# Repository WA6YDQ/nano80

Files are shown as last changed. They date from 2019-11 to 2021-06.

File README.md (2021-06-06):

nano80 - An Arduino powered 8080 single board computer.
======================

This is an 8080 simulator/emulator for an Arduino Nano. It uses about 
12K of memory and appx 600 bytes of ram (dynamic memory).

This is a front panel programmable computer, something like the 
single board trainers used in the 70's and 80's in colleges. 
Using a few switches and push buttons, along with some led's 
and a 1x8 lcd display, you can program the memory, step thru 
and view memory and run 8080 programs. There is a bootloader 
that allows loading an 8080 object coded program over the serial 
port as well as some development programs written in c.

See the schematic for wiring.

There is more detail on my blog at landfallnet.blogspot.com
Look for the nano80 entry.

I use a 32Kx8 FRAM for main memory. This slows it down a lot, but 
it gives you lots of room to play around. If you want more speed, 
change the fram.[read8/write8] to mem[] and set up about 1K of 
arduino ram. Doing this gives a speed improvement of about 4.5 times.

The serial port is defined so that your 8080 has a serial port in 
addition to 8 led's and 8 toggle switches for input/output.

The input/output ports are defined as follows:
- IN 0x00 is the toggle switches
- IN 0x01 is the serial port using the arduino
- IN 0x02 returns the number of available bytes on the serial port

- OUT 0x00 is the 8 LED's 
- OUT 0x01 is the serial port using the arduino

=========================
NOTE: The .c programs are utility programs that run on a linux computer
and are not part of the arduino code. Only put the .ino file into the
arduino workspace when building this project. 
==========================

------------------------------

I posted an 8080 opcode tester in diag.asm. This is a brute-force
8080 opcode tester. I've run this over several days with good results
(after I fixed the bugs). 

------------------------------

There is a boot loader in software to load intel .hex files 
into the nano80 memory. Loading more than a few bytes via switches
and lights get old fast. The boot loader lets you assemble large 
programs and upload then. See README.bootloader for use.

There are two programs used to create and send the .hexfiles:
- ihex.c
- upload.c

ihex converts the .com output of the assembler into intel .hex files.
upload is a serial based uploader that allows for the slow memory 
access of the FRAM memory chip.

To compile these 2 programs:
- cc -o ihex ihex.c
- cc -o upload upload.c

-----------------------------------

Also here is asm80.c

This is a command line 8080 assembler I wrote some time ago. Tested 
under Linux, compiled with gcc. To compile: 

- cc -o asm80 asm80.c

asm80 uses standard intel 8080 nmemonics. It is NOT a macro assembler.

-----------------------------------

There are some 8080 source code files for testing the system. 

- sertest.asm is a simple test of the serial port. 
- cylon.asm is a flashy lights program.

-----------------------------------

There is a program called dump.c This is a hex dump program 
I wrote to view object code files. 

Compile with:

- cc -o dump dump.c

-----------------------------------

MIT license applies to all files herein unless otherwise noted.

--Kurt

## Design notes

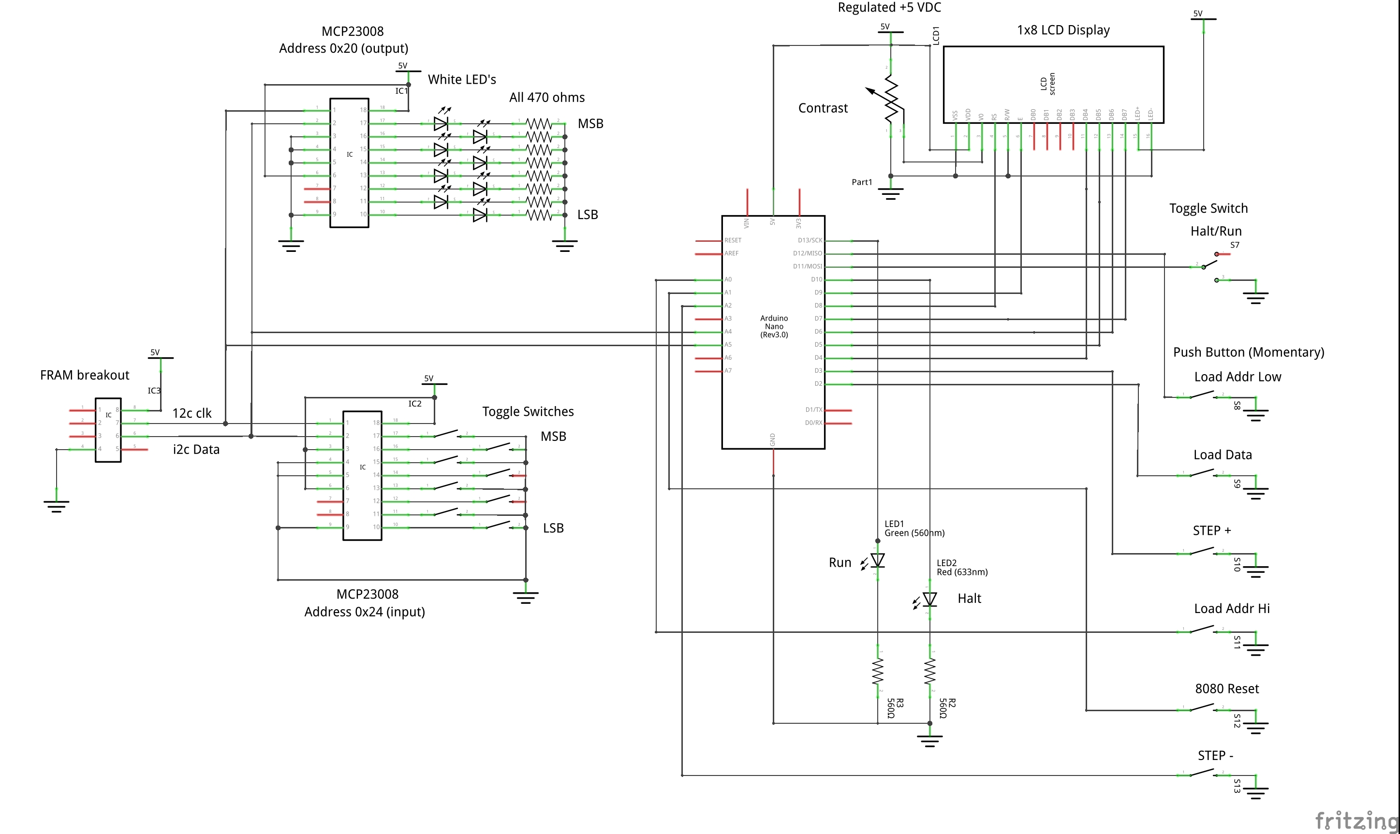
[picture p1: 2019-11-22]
nano80_schem.jpg

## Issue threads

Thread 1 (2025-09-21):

Arduino nanocircuits

alexanderbedoyahincapie058-sudo, 2025-09-21:

WA6YDQ, 2025-09-22:
No issue specified. Closing.

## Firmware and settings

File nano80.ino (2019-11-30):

/*
 * This is an 8080 simulator specifically for the
 * Arduino Nano. It uses an I2C 32K byte FRAM chip for main memory,
 * a front panel to program memory includinga 1x8 LCD, 8 toggle switches,
 * and 6 momentary buttons. The memory (non-volatile) is from 0000h thru 7fffh.
 * There is boot loader code to remotely program memory.
 * This makes a very good 8080 software development tool and play toy.
 * 
 * (C) k theis 11/2019 MIT license applies.
 * 
 * version 1.05  11/30/2019 DAA passes. All op codes passed the diag.asm check.
 * version 1.04e 11/29/2019 All instructions passed op code checker xcpt DAA.
 * version 1.04d 11/26/2019 Set parity flag (P) based on parity test, fix RLC,RRC,RAL
 * version 1.04c 11/26/2019 Change docs, removed unused vars. No functional changes.
 * version 1.04b 11/25/2019 fix things in debug() 
 * version 1.04a 11/25/2019 SBB: fix it right this time
 * version 1.04  11/25/2019 SBB: a=a-n-C change, added intel HEX bootloader. Uses custom backend
 * uploader w/20msec delays between HEX lines. Needed for FRAM.
 * version 1.03  11/22/2019 removed all bootloader code. fram access is too slow for it
 * version 1.02c 11/21/2019 fix issue with conditional return, shorten code
 * version 1.02b 11/21/2019 max baud 1200, fixed boot loader & serial read()
 * version 1.02a 11/20/2019 fixed bootloader byte sequence
 * version 1.02 11/20/2019 wrote inline bootloader, load/reset starts it
 * version 1.01 11/20/2019 minor change to reset()
 * version 1.0  11/18/2019 released to wild
 */

#include <string.h>
#include <LiquidCrystal.h>
#include <Wire.h>
#include <avr/pgmspace.h>
#include "Adafruit_FRAM_I2C.h"

#define MAXMEM 32768     // maximum RAM size
#define SERIALSPEED 9600 // Serial.write works till the buffer is filled.
                         // Because of slowwwww FRAM memory access, don't expect much. 
#define DEBUG 0          // 0: no debugging serial output (except at halt), 
                         // 1: show address and opcode on serial port while running

#define HALTLED 10       // D10 Halt LED
#define RUNLED 13        // D13 Run LED
#define RUNHALT 11       // D11 runhalt switch run=0, halt=1 (toggle switch)
#define RESET A1         // D13 reset switch (momentary switch)
#define LDAH A0          // load address high (momentary switch)
#define LDAL 12          // load address lo (momentary switch)
#define STEP 3           // increment address, show data (momentary switch)
#define LOAD 2           // load data into memory, step address (momentary switch)
#define STEPMINUS A2     // decrement address, show data (momentary switch)

#define e 9              // LCD display (1x8) control lines
#define rs 8
#define d7 7
#define d6 6
#define d5 5
#define d4 4

#define DEBOUNCE 80     // push button switch debounce time

uint16_t    PC, A, BC, DE, HL, StackP, temp, carry, hi, lo;
uint8_t     OP;
bool        C, Z, P, AC, S, INTE;


LiquidCrystal lcd(rs,e,d4,d5,d6,d7);
Adafruit_FRAM_I2C fram = Adafruit_FRAM_I2C();

/* send debugging info to the serial port */
void debug() {
    char crnt[strlen("PC:%4.4X  OP:%2.2X")+1];
    sprintf(crnt,"PC:%4.4X  OP:%2.2X",PC,OP);
    Serial.println(crnt);
    char regs[strlen("A:%2.2X  BC:%4.4X  DE:%4.4X  HL:%4.4X  SP:%4.4X")+1];
    sprintf(regs,"A:%2.2X  BC:%4.4X  DE:%4.4X  HL:%4.4X  SP:%4.4X",A,BC,DE,HL,StackP);
    Serial.println(regs);
    char flags[strlen("Z:%d  C:%d  S:%d  AC:%d  P:%d")+1];
    sprintf(flags,"Z:%d  C:%d  S:%d  AC:%d  P:%d",Z,C,S,AC,P);
    Serial.println(flags);
    Serial.println();
    return;
}

/* clear FRAM, then load the boot loader in hi memory */
void clrmem() {     // called from reset()
    uint16_t adr;
    uint8_t dat;
    lcd.home();
    lcd.print("Clr Mem ");
    /* first clear FRAM */
    for (adr=0; adr < 32768; adr++) 
        fram.write8(adr,0);
    lcd.clear();
    return;
}

/* read intel .hex records from the serial port  
 *  This needs a custom uploader (see upload.c in repository) to properly
 *  deal with the FRAM wait states. The uploader sends an intel HEX file
 *  line by line with a 20msec delay at the end of each line. This allows 
 *  time to send the data to the FRAM memory as well as dealing with the 
 *  limited ram buffer for the serial port.
 */
void bootload () {

    int cnt, bytenum, addr, recordtype, dat, cd = 0;
    uint8_t record[80];
    uint8_t tdat[4] = {0,0,0,0};
    lcd.home();
    lcd.print("booting ");
    /* main read & store loop */

    while (Serial.available() == 0) continue;   // wait for data  
dlloop:
    for (cnt=0;cnt<79;cnt++) record[cnt]=0;
    cd = 0;
    cnt = 0;
    if (Serial.available()==0) goto dlloop;
    while (1) {
        dat = Serial.read();
        if (dat == -1) continue;    // wait till data arrives
        if (dat == 0x3a) continue;  // start char
        if (dat == '\n') break;
        tdat[cd]=dat & 0xff;
        cd++;
        if (cd<2) continue;         // combine bytes
        cd = 0;
         if (tdat[0] > 0x39) tdat[0]-=7;        // convert from ascii
         tdat[0]-=0x30;
         if (tdat[1] > 0x39) tdat[1]-=7;
         tdat[1]-=0x30;
        record[cnt] = ((16*tdat[0]) + tdat[1]);
        output(record[cnt],0);      // display byte on LED's (eye candy)
        if (cnt==0) bytenum = record[0];    // 0 because we skip the ':'
        /* count=0  address=1-2   record type=3  bytenum+1=checksum */
        if (cnt==3) recordtype = record[3];
        cnt++;
    }
    if (recordtype == 0) {      // load data from DATA record type
        // now store the record
        addr = (256*record[1])+record[2];
        for (cd=0; cd<bytenum;cd++) {
            fram.write8(addr,record[cd+4]);
            addr++;
        }  
        goto dlloop;
    }
     // ignore record type other than 0 for now (will need for 8086 etc)

    output(0,0);        // clear the LED's
    lcd.home();
    lcd.print(addr,HEX);
    lcd.print("        ");
    delay(1000);
    lcd.home();
    lcd.print("Done    ");
    delay(1000);
    
    lcd.clear();
    return;
}


/* reset the processor */
void reset(void) {
    digitalWrite(RUNLED,0);     // turn OFF run led

    if (digitalRead(STEPMINUS) == 0) {  // press STEPMINUS and reset will
        clrmem();                       // clear memory (FRAM)
        while (digitalRead(STEPMINUS) == 0) { 
            delay(DEBOUNCE);
        }
        delay(DEBOUNCE);
    }

    if (digitalRead(LOAD) == 0) {
        bootload();
        while (digitalRead(LOAD) == 0) {
            delay(DEBOUNCE);
        }
        delay(DEBOUNCE);
    }


    // normal reset
    PC = A = BC = DE = HL = StackP = 0; // The real 8080 doesn't clear these
    Z = C = S = AC = P = INTE = 0;      // on reset. Remove this if you want.
                                        // (The Z80 DOES set some to FFFFh, ie. SP)

    digitalWrite(HALTLED, 0);   // turn OFF HALT led
    while (digitalRead(RESET) == 0) {
        delay(DEBOUNCE);
    }
    delay(DEBOUNCE);
    return;
}


/* show address/data (based on PC/OP) on a 1x8 LCD */
void updatelcd() {
    char lcd_addr[5];
    char lcd_data[3];
    lcd.clear();
    sprintf(lcd_addr,"%4.4X",PC);
    if (PC >= MAXMEM)   // account for missing memory
            OP=0x00;
        else
            OP = fram.read8(PC);
    sprintf(lcd_data,"%2.2X",OP);
    lcd.setCursor(0,0);
    lcd.print(lcd_addr);
    lcd.setCursor(6,0);
    lcd.print(lcd_data);
    return;
}

byte readSwitchPort() {
    byte val;
    Wire.beginTransmission(0x24); // address of input port
        Wire.write(0x09);
        Wire.endTransmission();
        Wire.requestFrom(0x24,1);
        while (Wire.available()) {            
            val = Wire.read();
        }
    return val;
}

void frontpanel() {
    uint16_t ADR;
    byte DAT;
    digitalWrite(RUNLED,0);     // turn off run led
    updatelcd();
    while (digitalRead(RUNHALT)==1) {   // loop while in stop mode
        if (digitalRead(RESET) == 0) {   // reset pressed?
            reset();
            return;
        }
        if (digitalRead(LDAH)==0) {     // Load Address high
            ADR = readSwitchPort();
            PC = (PC &0xFF) + (ADR*256);
            updatelcd();
            while (digitalRead(LDAH)==0) {
                delay(DEBOUNCE);
                continue;
            }
            delay(DEBOUNCE);
            continue;
        }
        if (digitalRead(LDAL) == 0) {   // Load Address lo
            ADR = readSwitchPort();
            PC = (PC & 0xFF00) + ADR;
            updatelcd();
            while (digitalRead(LDAH)==0) {
                delay(DEBOUNCE);
                continue;
            }
            delay(DEBOUNCE);
            continue;
        }
        if (digitalRead(STEP)==0) {     // inc PC, show mem
            PC += 1;
            updatelcd();
            while (digitalRead(STEP)==0) { 
                delay(DEBOUNCE);
                continue;
            }
            delay(DEBOUNCE);
            continue;
        }
        if (digitalRead(STEPMINUS)==0) {    // dec PC, show mem
            PC -= 1;
            updatelcd();
            while (digitalRead(STEPMINUS)==0) { 
                delay(DEBOUNCE);
                continue;
            }
            delay(DEBOUNCE);
            continue;   
        }
        if (digitalRead(LOAD)==0) {     // load into (PC) switches, inc PC
            DAT = readSwitchPort();
            fram.write8(PC,DAT);
            updatelcd();    // show updated value while switch pressed
            while (digitalRead(LOAD)==0) {
                delay(DEBOUNCE);
                continue;
            }
            delay(DEBOUNCE);
            PC += 1;
            updatelcd();        // show new value when switch released
            continue;
        }
        //
        
        continue;
    }
    delay(DEBOUNCE);
    lcd.clear();
    digitalWrite(RUNLED,1);     // turn on run led
    return;
}



void halt(void) {
    digitalWrite(RUNLED,0);     // turn off RUN led

    digitalWrite(HALTLED, 1);   // turn on HALT led
    debug();
    while (true) {
        if (digitalRead(RUNHALT) == 1) {
            frontpanel();
            digitalWrite(RUNLED,0);
        }
        if (digitalRead(RESET) == 0) {
            reset();
            break;
        }
    }
    delay(DEBOUNCE);
    digitalWrite(HALTLED,0);    // clear HALT led
    while (digitalRead(RESET) == 0) continue;
    delay(DEBOUNCE);
    return;

}



/* Get an 8080 register and return the value */
uint16_t getreg(uint16_t reg) {
    switch (reg) {
        case 0:     // B
            return ((BC >>8) & 0x00ff);
        case 1:     // C
            return (BC & 0x00ff);
        case 2:     // D
            return ((DE >>8) & 0x00ff);
        case 3:     // E
            return (DE & 0x00ff);
        case 4:     // H
            return ((HL >>8) & 0x00ff);
        case 5:     // L
            return (HL & 0x00ff);
        case 6:     // (HL)
            return fram.read8(HL);
        case 7:
            return (A);
        default:
            break;
    }
    return 0;
}


/* Put a value into an 8080 register from memory */
void putreg(uint16_t reg, uint16_t val)
{
    switch (reg) {
        case 0:
            BC = BC & 0x00FF;
            BC = BC | (val <<8);
            break;
        case 1:
            BC = BC & 0xFF00;
            BC = BC | val;
            break;
        case 2:
            DE = DE & 0x00FF;
            DE = DE | (val <<8);
            break;
        case 3:
            DE = DE & 0xFF00;
            DE = DE | val;
            break;
        case 4:
            HL = HL & 0x00FF;
            HL = HL | (val <<8);
            break;
        case 5:
            HL = HL & 0xFF00;
            HL = HL | val;
            break;
        case 6:
            fram.write8(HL,val & 0xff);
            break;
        case 7:
            A = val & 0xff;
        default:
            break;
    }
}



/* Return the value of a selected register pair */
int16_t getpair(int16_t reg)
{
    switch (reg) {
        case 0:
            return (BC);
        case 1:
            return (DE);
        case 2:
            return (HL);
        case 3:
            return (StackP);
        default:
            break;
    }
    return 0;
}



/* Put a value into an 8080 register pair */
void putpair(int16_t reg, uint16_t val) // was int16_t val
{
    switch (reg) {
        case 0:
            BC = val;
            break;
        case 1:
            DE = val;
            break;
        case 2:
            HL = val;
            break;
        case 3:
            StackP = val;
            break;
        default:
            break;
    }
}


/* Set flags based on val */
void setarith(int val) {
    if (val & 0x100)    // >= 256
        C = 1;
    else
        C = 0;
    if (val & 0x80) {   // negative
        S = 1;
    } else {
        S = 0;          // positive
    }
    if ((val & 0xff) == 0)
        Z = 1;
    else
        Z = 0;
    AC = 0;             // only true w/8080, not for Z80
    P = parity(val);

}

/* set flags after logical op */
void setlogical(int32_t reg)
{
    C = 0;      // always  (AND A opcode will clear CY)
    if (reg & 0x80) {
        S = 1;
    } else {
        S = 0;
    }
    if ((reg & 0xff) == 0)
        Z = 1;
      else
        Z = 0;
    AC = 0;
    P = parity(reg);
}
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
void loop() {  
begin:
    reset();    /* initialize everything but memory */
    digitalWrite(RUNLED,1);

    while (true) {
        if (digitalRead(RESET) == 0) goto begin;    // calling loop() resets the arduino, so we use a goto
        
        if (digitalRead(RUNHALT)) {
            delay(DEBOUNCE);
            frontpanel();  // if halt sw enabled, go to loader. Else run.
        }
        
        if (PC >= MAXMEM) // account for non-existant memory
            OP=0x00;
        else
            OP = fram.read8(PC);

        /* debugging - show address/opcode on serial port */
        if (DEBUG) {
            char tmpout[strlen("PC:%4.4X  OP:%2.2X")+1];
            sprintf(tmpout,"PC:%4.4X  OP:%2.2X",PC,OP);
            Serial.println(tmpout);
        }


        /* This is the instruction decoder. Decoding style is lifted from
         * https://github.com/simh/simh/blob/master/ALTAIR/altair_cpu.c
         * since it's smaller and cleaner than my orig code. I cleaned
         * up some things for this build, and tightened some code. 
        */


        if (OP == 0x76) {    // HLT, stop until reset
            halt(); 
            goto begin;     // restart at 0
        }

        if ((OP & 0xC0)==0x40) {                    // MOV DEST,SRC
            temp = getreg(OP & 0x07);               // read from reg
            putreg((OP >> 3) & 0x07, temp);         // save to reg
            PC += 1;
            continue;
        }

        if ((OP & 0xC7)==0x06) {                  // MVI nn
            putreg((OP >> 3) & 0x07, fram.read8(PC+1));
            PC += 2;
            continue;
        }


        if ((OP & 0xCF) == 0x01) {                  // LXI nn
            temp = fram.read8(++PC);
            temp += (fram.read8(++PC) * 256);
            putpair(((OP >> 4) & 0x03), temp);
            PC += 1;
            continue;
        }

        if ((OP & 0xEF) == 0x0A) {                  // LDAX
            temp = getpair((OP >> 4) & 0x03);
            putreg(7, fram.read8(temp));
            PC += 1;
            continue;
        }

        if ((OP & 0xEF) == 0x02) {                  // STAX
            temp = getpair((OP >> 4) & 0x03);
            fram.write8(temp,getreg(7)); 
            PC += 1;
            continue;
        }

        /* opcodes with tests */
        
        if ((OP & 0xF8) == 0xB8) {                  // CMP
            temp = A & 0xFF;
            temp -= getreg(OP & 0x07);
            setarith(temp);
            PC += 1;
            continue;
        }

        if ((OP & 0xC7) == 0xC2) {                  // JMP <condition>
            if (cond((OP >> 3) & 0x07) == 1) {
                lo = fram.read8(++PC);
                hi = fram.read8(++PC);
                PC = (hi << 8) + lo;
            } else {
                PC += 3;
            }
            continue;
        }


        if ((OP & 0xC7) == 0xC4) {                  // CALL <condition>
            if (cond((OP >> 3) & 0x07) == 1) {
                lo = fram.read8(++PC);
                hi = fram.read8(++PC);
                PC++;
                fram.write8(--StackP,(PC & 0xff00) >> 8);
                fram.write8(--StackP,(PC & 0xff));
                //PC = (hi << 8) + lo;
                PC = (hi * 256) + lo;
            } else {
                PC += 3;
            }
            continue;
        }

        if ((OP & 0xC7) == 0xC0) {                  // RET <condition>
            if (cond((OP >> 3) & 0x07) == 1) {
                PC = fram.read8(StackP);
                StackP++;
                PC |= ((fram.read8(StackP) << 8) & 0xff00);
                StackP++;
            } else {
                PC += 1;
            }
            continue;
        }

        if ((OP & 0xC7) == 0xC7) {                  // RST
            StackP--;
            fram.write8(StackP,(PC >> 8) & 0xff);
            StackP--;
            fram.write8(StackP,PC & 0xff);
            PC = OP & 0x38;
            continue;
        }


        if ((OP & 0xCF) == 0xC5) {                  // PUSH
            temp = getpush((OP >> 4) & 0x03);
            StackP--;
            fram.write8(StackP,(temp >> 8) & 0xff);
            StackP--;
            fram.write8(StackP,temp & 0xff);
            PC += 1;
            continue;
        }


        if ((OP & 0xCF) == 0xC1) {                   // POP
            temp = fram.read8(StackP);
            StackP++;
            temp |= fram.read8(StackP) << 8;
            StackP++;
            putpush((OP >> 4) & 0x03, temp);
            PC += 1;
            continue;
        }

        if ((OP & 0xF8) == 0x80) {                  // ADD
            A += getreg(OP & 0x07);
            setarith(A);
            A = A & 0xFF;
            PC += 1;
            continue;
        }

        if ((OP & 0xF8) == 0x88) {                  // ADC
            carry = 0;
            if (C) carry = 1;
            A += getreg(OP & 0x07);
            A += carry;
            setarith(A);
            A = A & 0xFF;
            PC += 1;
            continue;
        }

        if ((OP & 0xF8) == 0x90) {                  // SUB
            A -= getreg(OP & 0x07);
            setarith(A);
            A = A & 0xFF;
            PC += 1;
            continue;
        }

        if ((OP & 0xF8) == 0x98) {                  // SBB
            carry = 0;
            if (C) carry = 1;
            A = A - getreg(OP & 0x07) - carry;
            setarith(A);
            A = A & 0xFF;
            PC += 1;
            continue;
        }

        if ((OP & 0xC7) == 0x04) {                  // INR
            temp = getreg((OP >> 3) & 0x07);
            temp++;
            setinc(temp);
            temp = temp & 0xFF;
            putreg((OP >> 3) & 0x07, temp);
            PC += 1;
            continue;
        }

        if ((OP & 0xC7) == 0x05) {                  // DCR
            temp = getreg((OP >> 3) & 0x07);
            temp--;
            setinc(temp);
            temp = temp & 0xFF;
            putreg((OP >> 3) & 0x07, temp);
            PC += 1;
            continue;
        }

        if ((OP & 0xCF) == 0x03) {                  // INX
            temp = getpair((OP >> 4) & 0x03);
            temp++;
            temp = temp & 0xFFFF;
            putpair((OP >> 4) & 0x03, temp);
            PC += 1;
            continue;
        }
        
        if ((OP & 0xCF) == 0x0B) {                  // DCX
            temp = getpair((OP >> 4) & 0x03);
            temp--;
            temp = temp & 0xFFFF;
            putpair((OP >> 4) & 0x03, temp);
            PC += 1;
            continue;
        }

        if ((OP & 0xCF) == 0x09) {                  // DAD
            C = 0;
            if (long(HL) + long(getpair((OP >> 4) & 0x03) > 0xffff))
                C = 1;
            HL += getpair((OP >> 4) & 0x03);
            PC += 1;
            continue;
        }

        if ((OP & 0xF8) == 0xA0) {                  // ANA
            A &= getreg(OP & 0x07);
            C = 0;
            setlogical(A);
            A &= 0xFF;
            PC += 1;
            continue;
        }

        if ((OP & 0xF8) == 0xB0) {                  // ORA
            A |= getreg(OP & 0x07);
            C = 0;
            setlogical(A);
            A &= 0xFF;
            PC += 1;
            continue;
        }
        
        
        if ((OP & 0xF8) == 0xA8) {                  // XRA
            A ^= getreg(OP & 0x07);
            C = 0;
            setlogical(A);
            A &= 0xFF;
            PC += 1;
            continue;
        }

        /* now do the rest of the instructions */

        switch(OP) {

            case 0xfe: {                        // CPI
                temp = A & 0xFF;
                temp -= fram.read8(++PC);
                PC += 1;
                setarith(temp);
                break;
            }

            case 0xe6: {                        // ANI
                A &= fram.read8(++PC);
                PC += 1;
                C = AC = 0;
                setlogical(A);
                A &= 0xFF;
                break;
            }

            case 0xee: {                        // XRI
                A ^= fram.read8(++PC);
                PC += 1;
                C = AC = 0;
                setlogical(A);
                A &= 0xFF;
                break;
            }

            case 0xf6: {                        // ORI
                A |= fram.read8(++PC);
                PC += 1;
                C = AC = 0;
                setlogical(A);
                A &= 0xFF;
                break;
            }
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

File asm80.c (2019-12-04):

/*
 
---------------------------------------- 
asm80.c	8080 assembler
version 4.2
07-13-2008	<theis.kurt@gmail.com> 	


Revised 12/2019 - allow loading . before certain key words 
(.db, .equ etc)

Revised 9/2/2008 - better error checking



This has more error checking, all the 
directives work as they should, and
labels can be used for almost anything.

I'm releasing this as GNU GPL 3 license. 
If you find this useful, send me a note. 
Also if you find any errors, please
let me know.

To compile this use:
cc -o asm80 asm80.c
on (hopefully) any c compiler.

This was done on a Linux system, but 
should work just fine on anything else.

To assemble a program:
asm80 file.asm
Will produce 2 files:
file.prn (print out file)
file.com (com format)

-----------------------------------------

*/



#include <stdio.h>
#include <stdlib.h>
#include <string.h>
#include <ctype.h>
#include <stdarg.h>

#define DEBUG 0			/* 1=debugging turned on, 0=off */
#define MAXTOKEN 100000		/* no more than 100K tokens */
#define MAXLABEL 10000		/* no more than 10K labels */
#define NOP_CODE 0		/* code for nop op-code for 8080 */
#define MAXLINE	 74		/* max line length of quoted string */

int tokenCount = 0;		/* count the number of tokens in input file */
int address = 0;		/* running count used in PASS 2 and 3 */
int *label_address;		/* assign address to a label */
int label_count = 0;		/* count the number of labels found/used */
int codenum = 0;		/* opcode value used in PASS 3 */
int idx = 0;			/* index counter used in PASS 3 */
int *memory;			/* array holding all assembled data */
int addr, addr1, addr2;		/* used to determine 3 byte opcode labels */
int NCFLAG = 0;			/* command line option - remove colon from label (see below comments) */
int FLAG = 0;			/* Gen Purpose FLAG */
int maxAddress = 0;		/* address at end of PASS 2 - used to set memory in PASS 3 */
int ERRFLAG = 0;		/* set if fatal errors found during assembly */

char sourceFile[80];		/* name of source code filename */
char printFile[80];		/* name of print filename */
char objFile[80];		/* name of object filename */
char token[MAXTOKEN][120];	/* used in PASS 1 */
char ptoken[MAXTOKEN][120];	/* processed tokens */
char singleWord[120];		/* used in PASS 1 */
char singleByte;		/* used in PASS 1 */
char label[MAXLABEL][80];	/* hold labels - max length 80 characters */


/* multi byte op codes are like mov a,b, jmp xxx, pop bc, etc */
/* single byte op codes are like nop, stc, ret */ 
/* these are multi-byte op codes (used in isMbyteOpCode) */
char mbopcode[20][5] = {"mov","mvi","ldax","stax","lxi","push","pop", \
			"add","sub","inr","dcr","cmp","ana","ora","xra","adc", \
			"sbb","dad","inx","dcx"};

/* assign list of opcodes to variables */

int opcode_bytes[256] = { \
1,3,1,1,1,1,2,1,1,1,1,1,1,1,2,1,1,3,1,1,1,1,2, \
1,1,1,1,1,1,1,2,1,1,3,3,1,1,1,2,1,1,1,3,1,1,1,2, \
1,1,3,3,1,1,1,2,1,1,1,3,1,1,1,2,1,1,1,1,1,1,1,1, \
1,1,1,1,1,1,1,1,1,1,1,1,1,1,1,1,1,1,1,1,1,1,1,1, \
1,1,1,1,1,1,1,1,1,1,1,1,1,1,1,1,1,1,1,1,1,1,1,1, \
1,1,1,1,1,1,1,1,1,1,1,1,1,1,1,1,1,1,1,1,1,1,1,1, \
1,1,1,1,1,1,1,1,1,1,1,1,1,1,1,1,1,1,1,1,1,1,1,1, \
1,1,1,1,1,1,1,1,1,1,1,1,1,1,1,1,1,1,1,1,1,1,1,1, \
1,1,1,3,3,3,1,2,1,1,1,3,1,3,3,2,1,1,1,3,2,3,1,2, \
1,1,1,3,2,3,1,2,1,1,1,3,1,3,1,2,1,1,1,3,1,3,1,2, \
1,1,1,3,1,3,1,2,1,1,1,3,1,3,1,2,1 };

char opcodes[256][10] = { \
"nop", "lxi b", "stax b", "inx b", "inr b", "dcr b", \
"mvi b", "rlc", "__8", "dad b", "ldax b", "dcx b", \
"inr c", "dcr c", "mvi c", "rrc", "_10", "lxi d", \
"stax d", "inx d", "inr d", "dcr d", "mvi d", "ral", \
"_18", "dad d", "ldax d", "dcx d", "inr e", "dcr e", \
"mvi e", "rar", "_20", "lxi h", "shld", "inx h", \
"inr h", "dcr h", "mvi h", "daa", "_28", "dad h", \
"lhld", "dcx h", "inr l", "dcr l", "mvi l", "cma", \
"_30", "lxi sp", "sta", "inx sp", "inr m", "dcr m", \
"mvi m", "stc", "_38", "dad sp", "lda", "dcx sp", \
"inr a", "dcr a", "mvi a", "cmc", "mov b,b", "mov b,c", \
"mov b,d", "mov b,e", "mov b,h", "mov b,l", "mov b,m", "mov b,a", \
"mov c,b", "mov c,c", "mov c,d", "mov c,e", "mov c,h", "mov c,l", \
"mov c,m", "mov c,a", "mov d,b", "mov d,c", "mov d,d", "mov d,e", \
"mov d,h", "mov d,l", "mov d,m", "mov d,a", "mov e,b", "mov e,c", \
"mov e,d", "mov e,e", "mov e,h", "mov e,l", "mov e,m", "mov e,a", \
"mov h,b", "mov h,c", "mov h,d", "mov h,e", "mov h,h", "mov h,l", \
"mov h,m", "mov h,a", "mov l,b", "mov l,c", "mov l,d", "mov l,e", \
"mov l,h", "mov l,l", "mov l,m", "mov l,a", "mov m,b", "mov m,c", \
"mov m,d", "mov m,e", "mov m,h", "mov m,l", "hlt", "mov m,a", \
"mov a,b", "mov a,c", "mov a,d", "mov a,e", "mov a,h", "mov a,l", \
"mov a,m", "mov a,a", "add b", "add c", "add d", "add e", \
"add h", "add l", "add m", "add a", "adc b", "adc c", \
"adc d", "adc e", "adc h", "adc l", "adc m", "adc a", \
"sub b", "sub c", "sub d", "sub e", "sub h", "sub l", \
"sub m", "sub a", "sbb b", "sbb c", "sbb d", "sbb e", \
"sbb h", "sbb l", "sbb m", "sbb a", "ana b", "ana c", \
"ana d", "ana e", "ana h", "ana l", "ana m", "ana a", \
"xra b", "xra c", "xra d", "xra e", "xra h", "xra l", \
"xra m", "xra a", "ora b", "ora c", "ora d", "ora e", \
"ora h", "ora l", "ora m", "ora a", "cmp b", "cmp c", \
"cmp d", "cmp e", "cmp h", "cmp l", "cmp m", "cmp a", \
"rnz", "pop b", "jnz", "jmp", "cnz", "push b", \
"adi", "rst 0", "rz", "ret", "jz", "_cb", \
"cz", "call", "aci", "rst 1", "rnc", "pop d", \
"jnc", "out", "cnc", "push d", "sui", "rst 2", \
"rc", "_d9", "jc", "in", "cc", "_dd", \
"sbi", "rst 3", "rpo", "pop h", "jpo", "xthl", \
"cpo", "push h", "ani", "rst 4", "rpe", "pchl", \
"jpe", "xchg", "cpe", "_ed", "xri", "rst 5", \
"rp", "pop psw", "jp", "di", "cp", "push psw", \
"ori", "rst 6", "rm", "sphl", "jm", "ei", \
"cm", "_fd", "cpi", "rst 7" };



FILE *sourcefile, *objfile, *prnfile;

/* ---------------------------------------------- */
/* ------------- Code Starts Here --------------- */
/* ---------------------------------------------- */


/*
*	isReserved() -  check if passed value is a reserved
*			word or character. Typically an opcode
*			or some such.
*
*/
int isReserved(char *token){	/* return 1 if match to reserved work, 0 if not */
int n;
const char reserved[21][8] = {"db",".db","DB",".DB", \
    		   "ds",".ds","DS",".DS", \
	           "dw",".dw","DW",".DW", \
     		   "org",".org","ORG",".ORG", \
		   "equ",".equ","EQU",".EQU"};

	for (n=0; n<255; n++){
		if (strcmp(token,opcodes[n])==0)	// test all opcodes
			return 1;
	}

	for (n=0; n<20; n++) {
		if (strcmp(token,reserved[n])==0)	// other reserved words
		    	return 1;
	}

	return 0;	/* everything else is OK */
}




/*
*	isOpcode() - check if passed value is a valid
*	opcode in 8080 format. If not, return -1
*	else return the size of the opcode, 1, 2 or 3
*/

int isOpcode(char *token){	/* check if opcode - return byte size or -1 */
int n;
	for (n=0; n<256; n++)
		if (strcmp(token,opcodes[n])==0)
			return opcode_bytes[n];
	return -1;	/* token not an opcode */
}
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

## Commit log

2019-11-18 8080 assembler program
2019-11-18 Assembler README
2019-11-19 Changed serial port driver and baud rate
2019-11-20 v1.01 minor change to reset()
    [nano80.ino]
2019-11-21 Changes to the bootloader and reset()
    [nano80.ino]
2019-11-21 fix conditional return instruction, tighten code
    [nano80.ino]
2019-11-22 Schematics - fritzing and image files
    [nano80.fzz]
2019-11-25 Tightened code, remove cruft
2019-12-04 8080 Assembler - see README.asm for use
